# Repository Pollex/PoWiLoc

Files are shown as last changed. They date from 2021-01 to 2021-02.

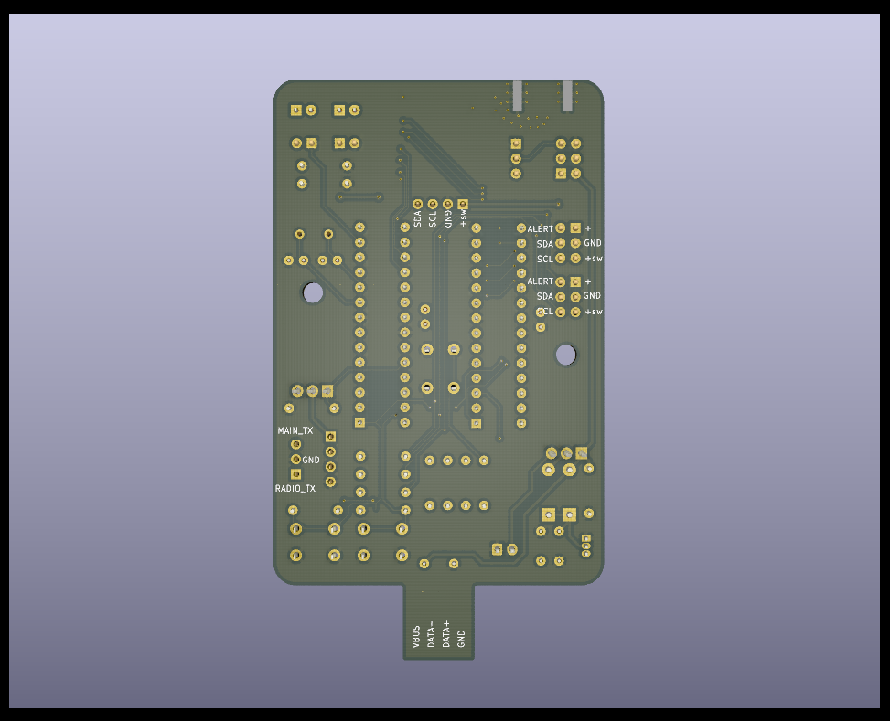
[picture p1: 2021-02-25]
hardware/exports/back_render.png

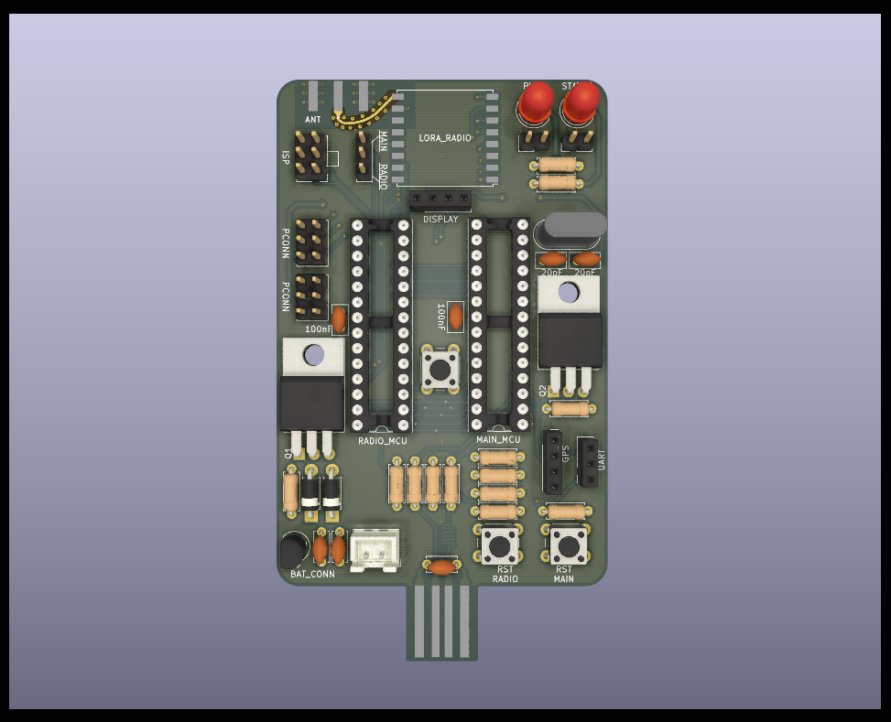
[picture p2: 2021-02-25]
hardware/exports/front_render.png

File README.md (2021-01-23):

# PoWiLoc
Pollex' Wireless Locator (PoWi Locator) is a fully Open-Source device used to test LoRaWAN connections and map them on the PoWi website and/or the [TTN Mapper](https://ttnmapper.org/) website.

The locator is designed to be built by everyone who has some technical knowledge (soldering and programming) and the device has several optional features which can be left out to make assembling the device easier.

The hardware is designed in free and Open-Source software called [KiCAD](https://kicad.org/).

The source code for this device is developed in [Visual Studio Code](https://code.visualstudio.com/) (a lightweight editor) with the [PlatformIO](https://platformio.org/) extension. Also both free and Open-Source. This setup is chosen instead of the Arduino IDE because it allows  for cleaner code and better library management.

## This project is in active development and contributions cannot be received at this point in time. As soon as a minimum viable product is built, contributions will open and links to documentation will be provided.

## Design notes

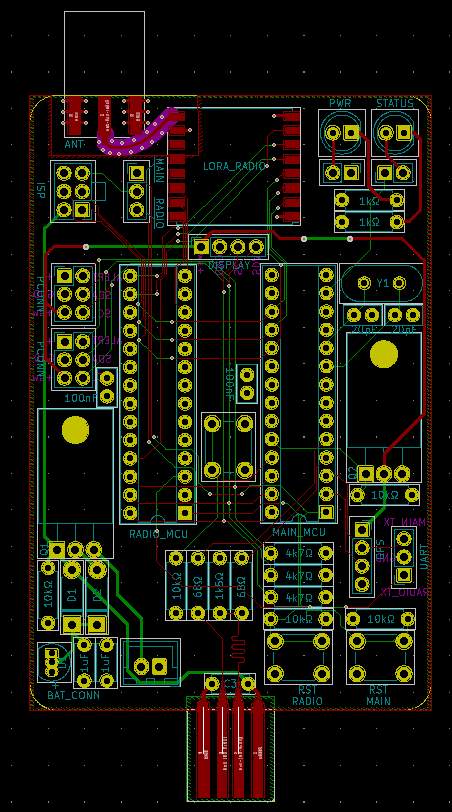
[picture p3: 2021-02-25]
hardware/exports/pcb.png

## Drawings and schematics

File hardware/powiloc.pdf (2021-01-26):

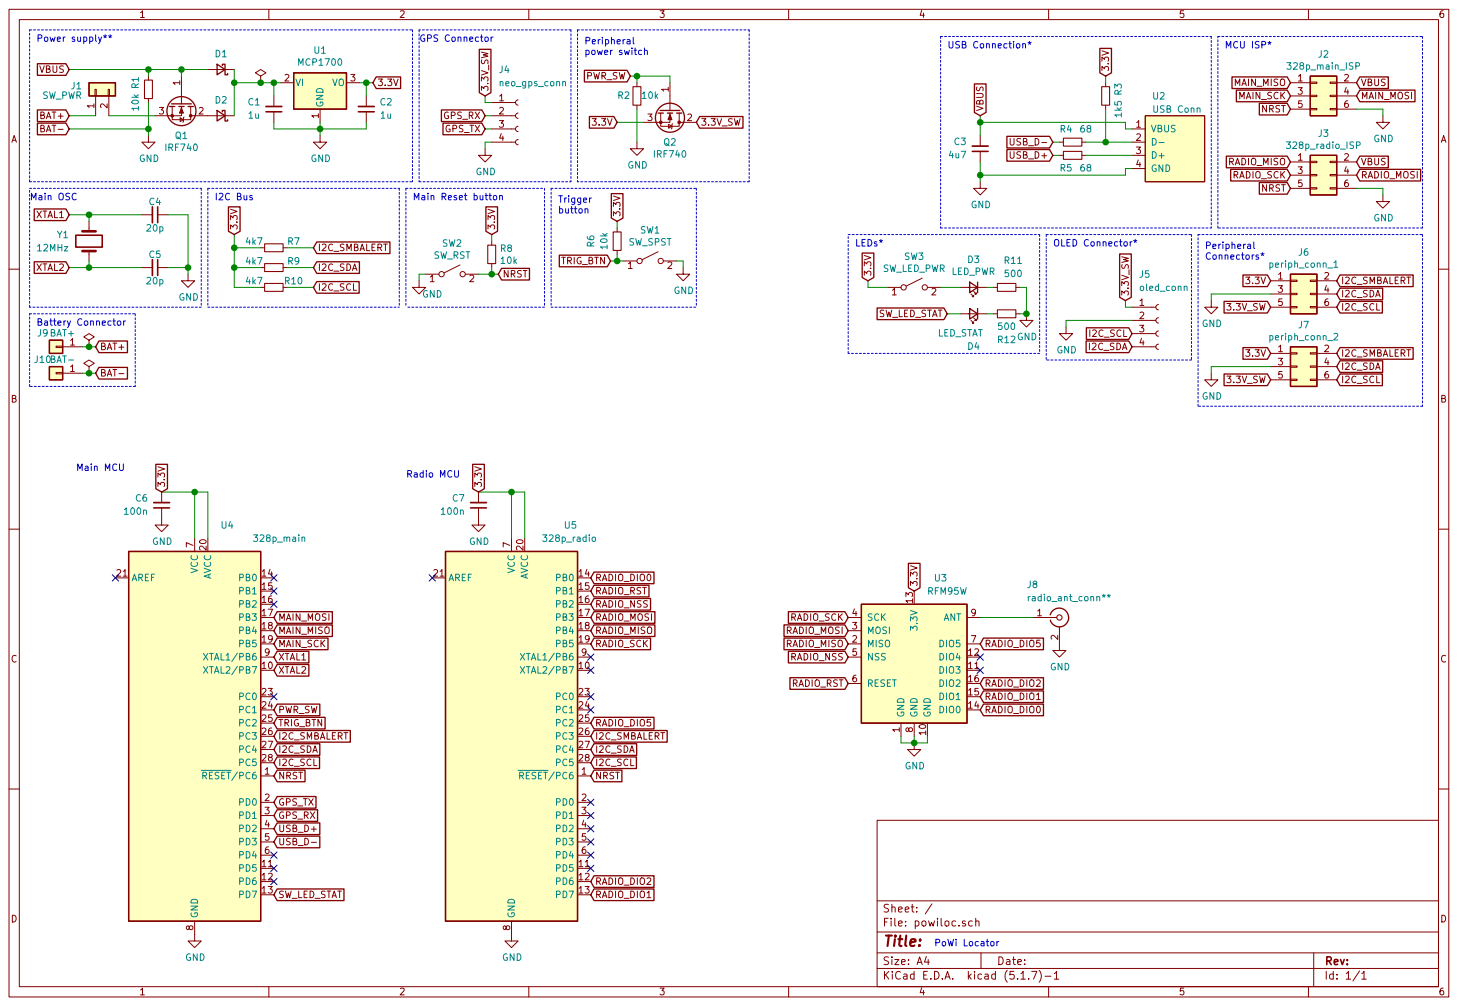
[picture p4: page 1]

1 GND 10 DIO3 11 DIO4 12 3.3V 13 DIO0 14 DIO1 15 DIO2 16 MISO 2 MOSI 3 SCK 4 NSS 5 RESET 6 DIO5 7 GND

File: powiloc.sch Sheet: /
Id: 1/1 Title:

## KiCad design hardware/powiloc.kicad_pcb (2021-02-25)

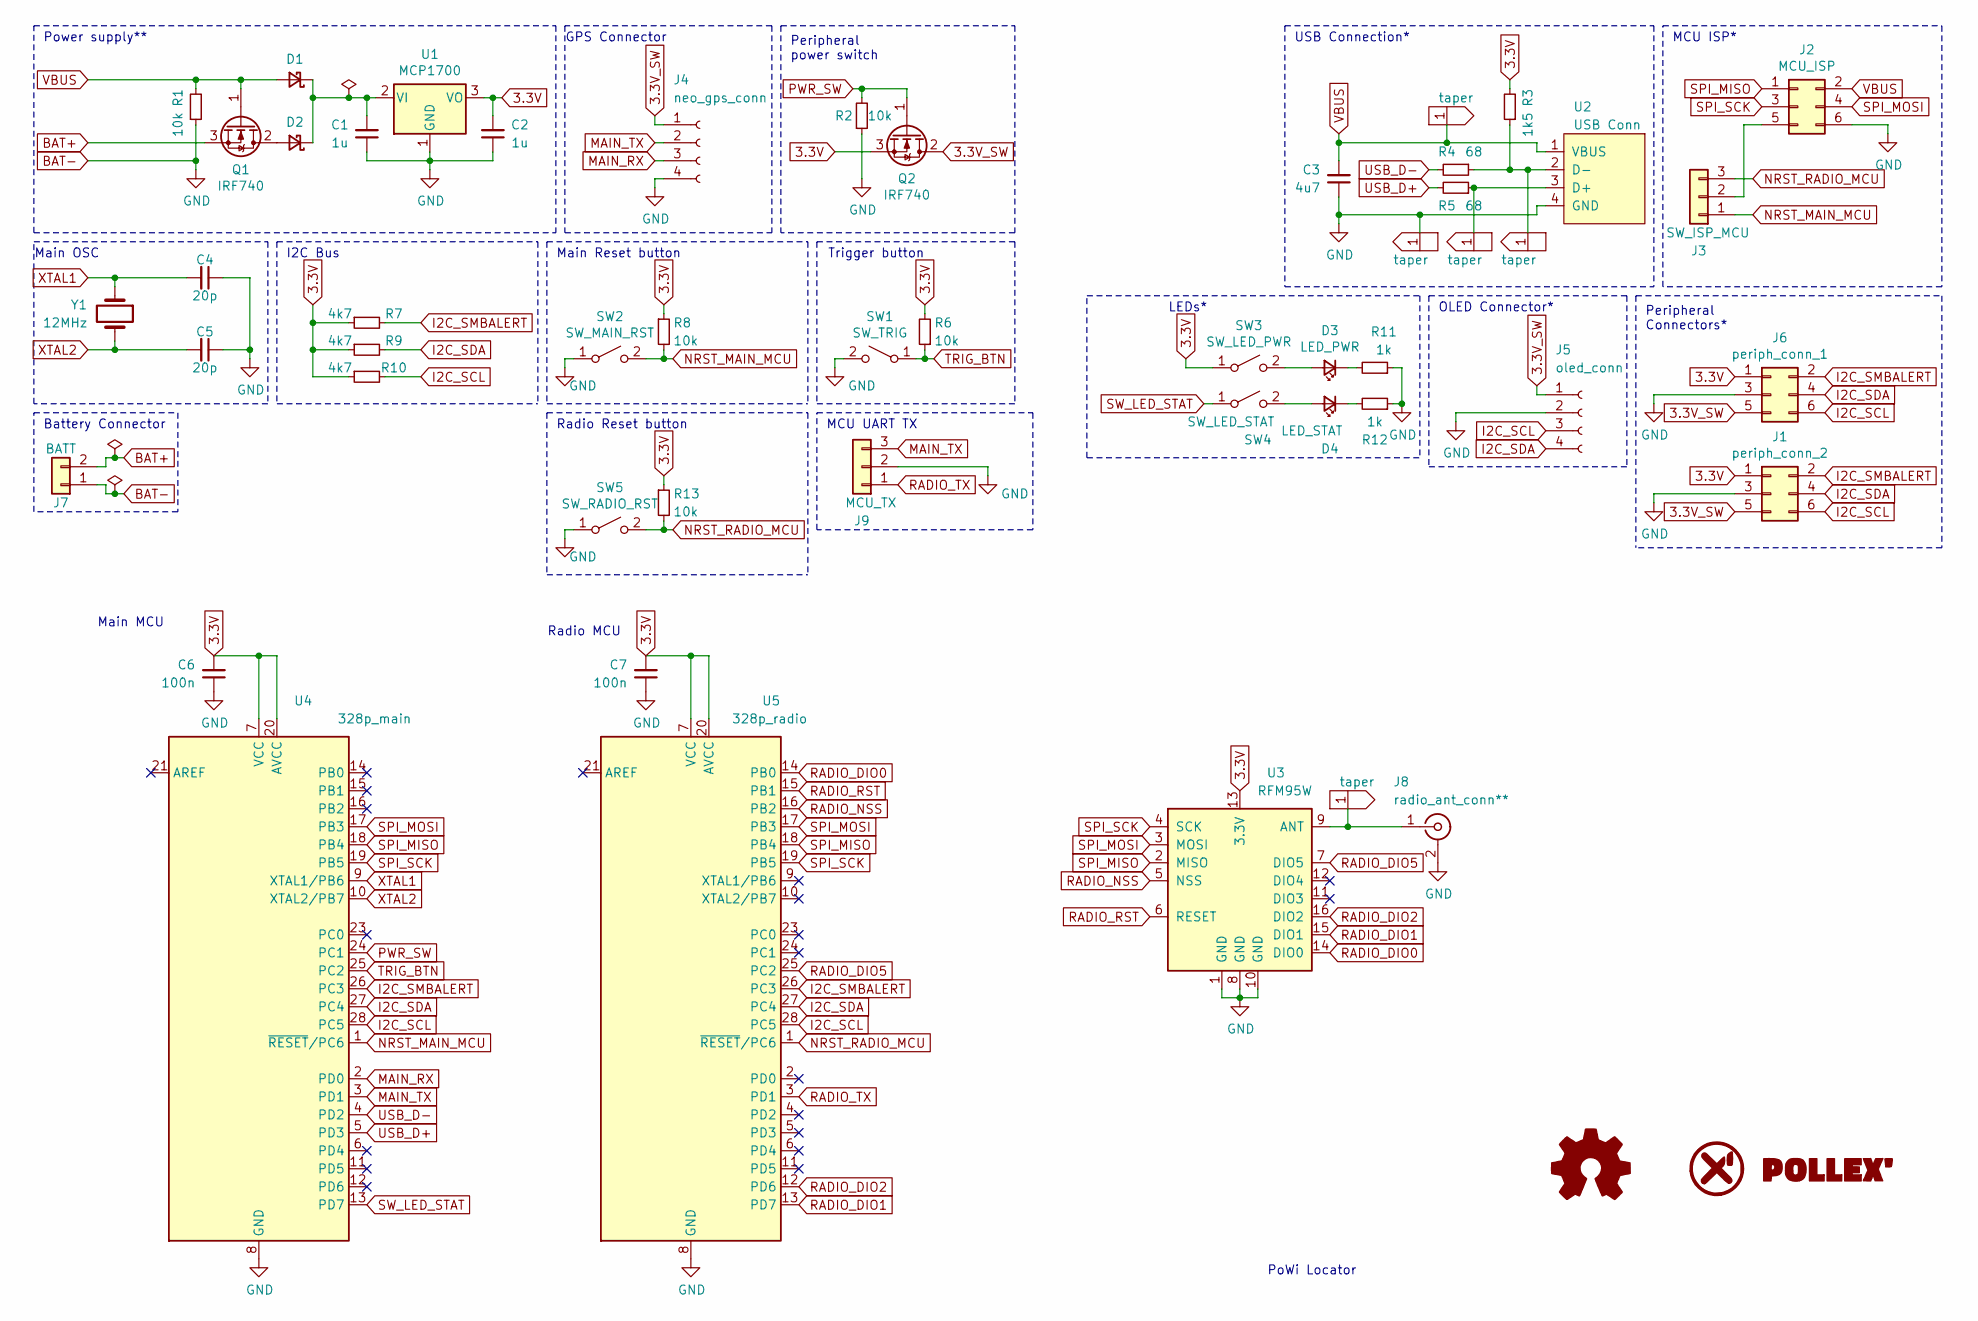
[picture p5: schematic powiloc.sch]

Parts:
C1, C2: 1u; C_Disc_D5.0mm_W2.5mm_P5.00mm
C3: 4u7; C_Disc_D5.0mm_W2.5mm_P5.00mm
C4, C5: 20p; C_Disc_D5.0mm_W2.5mm_P2.50mm
C6, C7: 100n; C_Disc_D5.0mm_W2.5mm_P2.50mm
D1, D2: D_Schottky_Small; D_DO-41_SOD81_P7.62mm_Horizontal
D3: LED_PWR; LED_D5.0mm
D4: LED_STAT; LED_D5.0mm
J1: periph_conn_2; PinHeader_2x03_P2.54mm_Vertical
J2: MCU_ISP; PinHeader_2x03_P2.54mm_Vertical
J3: SW_ISP_MCU; PinHeader_1x03_P2.54mm_Vertical
J4: neo_gps_conn; PinSocket_1x04_P2.54mm_Vertical
J5: oled_conn; PinSocket_1x04_P2.54mm_Vertical
J6: periph_conn_1; PinHeader_2x03_P2.54mm_Vertical
J7: BATT; JST_XH_B2B-XH-A_1x02_P2.50mm_Vertical
J8: radio_ant_conn**; SMA_Amphenol_132289_EdgeMount
J9: MCU_TX; PinSocket_1x03_P2.54mm_Vertical
Q1, Q2: IRF740; TO-220-3_Horizontal_TabDown
R1, R2, R6, R8, R13: 10k; R_Axial_DIN0207_L6.3mm_D2.5mm_P7.62mm_Horizontal
R3: 1k5; R_Axial_DIN0207_L6.3mm_D2.5mm_P7.62mm_Horizontal
R4, R5: 68; R_Axial_DIN0207_L6.3mm_D2.5mm_P7.62mm_Horizontal
R7, R9, R10: 4k7; R_Axial_DIN0207_L6.3mm_D2.5mm_P7.62mm_Horizontal
R11, R12: 1k; R_Axial_DIN0207_L6.3mm_D2.5mm_P7.62mm_Horizontal
SW1: SW_TRIG; SW_PUSH_6mm
SW2: SW_MAIN_RST; SW_PUSH_6mm
SW3: SW_LED_PWR; PinHeader_1x02_P2.54mm_Vertical
SW4: SW_LED_STAT; PinHeader_1x02_P2.54mm_Vertical
SW5: SW_RADIO_RST; SW_PUSH_6mm
T1, T2, T5: taper; uwT0.50_0.40_1.00_1.46_1.20
T3, T4: taper; uwT0.50_0.15_1.00_1.24_3.00
U1: MCP1700; TO-92_Inline
U2: USB Conn; USBPCB
U3: RFM95W; HOPERF_RFM9XW_SMD
U4: 328p_main; DIP-28_W7.62mm_Socket
U5: 328p_radio; DIP-28_W7.62mm_Socket
Y1: 12MHz; Crystal_HC49-U_Vertical

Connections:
3.3V: C2.2, C6.2, C7.2, J1.1, J6.1, Q2.3 (S), R3.2, R6.2, R7.1, R8.1, R9.1, R10.1, R13.1, SW3.1 (A), U1.3 (VO), U3.13 (3.3V), U4.7 (VCC), U4.20 (AVCC), U5.7 (VCC), U5.20 (AVCC)
3.3V_SW: J1.5, J4.1, J5.1, J6.5, Q2.2 (D)
BAT+: J7.2, Q1.3 (S)
BAT-: C1.1, C2.1, C3.1, C4.1, C5.1, C6.1, C7.1, J1.3, J2.6, J4.4, J5.2, J6.3, J7.1, J8.2 (Ext), J9.2, R1.1, R2.1, R11.1, R12.1, SW1.2 (B), SW2.1 (A), SW5.1 (A), T2.1, U1.1 (GND), U2.4 (GND), U3.1 (GND), U3.8 (GND), U3.10 (GND), U4.8 (GND), U4.22 (GND), U5.8 (GND), U5.22 (GND)
I2C_SCL: J1.6, J5.3, J6.6, R10.2, U4.28 (PC5), U5.28 (PC5)
I2C_SDA: J1.4, J5.4, J6.4, R9.2, U4.27 (PC4), U5.27 (PC4)
I2C_SMBALERT: J1.2, J6.2, R7.2, U4.26 (PC3), U5.26 (PC3)
MAIN_RX: J4.3, U4.2 (PD0)
MAIN_TX: J4.2, J9.3, U4.3 (PD1)
NRST_MAIN_MCU: J3.1, R8.2, SW2.2 (B), U4.1 (~RESET~/PC6)
NRST_RADIO_MCU: J3.3, R13.2, SW5.2 (B), U5.1 (~RESET~/PC6)
unnamed: C1.2, D1.1 (K), D2.1 (K), U1.2 (VI)
unnamed: D2.2 (A), Q1.2 (D)
unnamed: D3.1 (K), R11.2
unnamed: D3.2 (A), SW3.2 (B)
unnamed: D4.1 (K), R12.2
unnamed: D4.2 (A), SW4.2 (B)
unnamed: J2.5, J3.2
unnamed: J8.1 (In), T5.1, U3.9 (ANT)
unnamed: R3.1, R4.1, T4.1, U2.2 (D-)
unnamed: R5.1, T3.1, U2.3 (D+)
PWR_SW: Q2.1 (G), R2.2, U4.24 (PC1)
RADIO_DIO0: U3.14 (DIO0), U5.14 (PB0)
RADIO_DIO1: U3.15 (DIO1), U5.13 (PD7)
RADIO_DIO2: U3.16 (DIO2), U5.12 (PD6)
RADIO_DIO5: U3.7 (DIO5), U5.25 (PC2)
RADIO_NSS: U3.5 (NSS), U5.16 (PB2)
RADIO_RST: U3.6 (RESET), U5.15 (PB1)
RADIO_TX: J9.1, U5.3 (PD1)
SPI_MISO: J2.1, U3.2 (MISO), U4.18 (PB4), U5.18 (PB4)
SPI_MOSI: J2.4, U3.3 (MOSI), U4.17 (PB3), U5.17 (PB3)
SPI_SCK: J2.3, U3.4 (SCK), U4.19 (PB5), U5.19 (PB5)
SW_LED_STAT: SW4.1 (A), U4.13 (PD7)
TRIG_BTN: R6.1, SW1.1 (A), U4.25 (PC2)
USB_D+: R5.2, U4.5 (PD3)
USB_D-: R4.2, U4.4 (PD2)
VBUS: C3.2, D1.2 (A), J2.2, Q1.1 (G), R1.2, T1.1, U2.1 (VBUS)
XTAL1: C4.2, U4.9 (XTAL1/PB6), Y1.1
XTAL2: C5.2, U4.10 (XTAL2/PB7), Y1.2

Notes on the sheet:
Main OSC
Main MCU
Main Reset button
PoWi Locator
USB Connection*
Power supply**
MCU ISP*
GPS Connector
OLED Connector*
Trigger button
Radio MCU
I2C Bus
Peripheral power switch
LEDs*
Peripheral Connectors*
Battery Connector
Radio Reset button
MCU UART TX

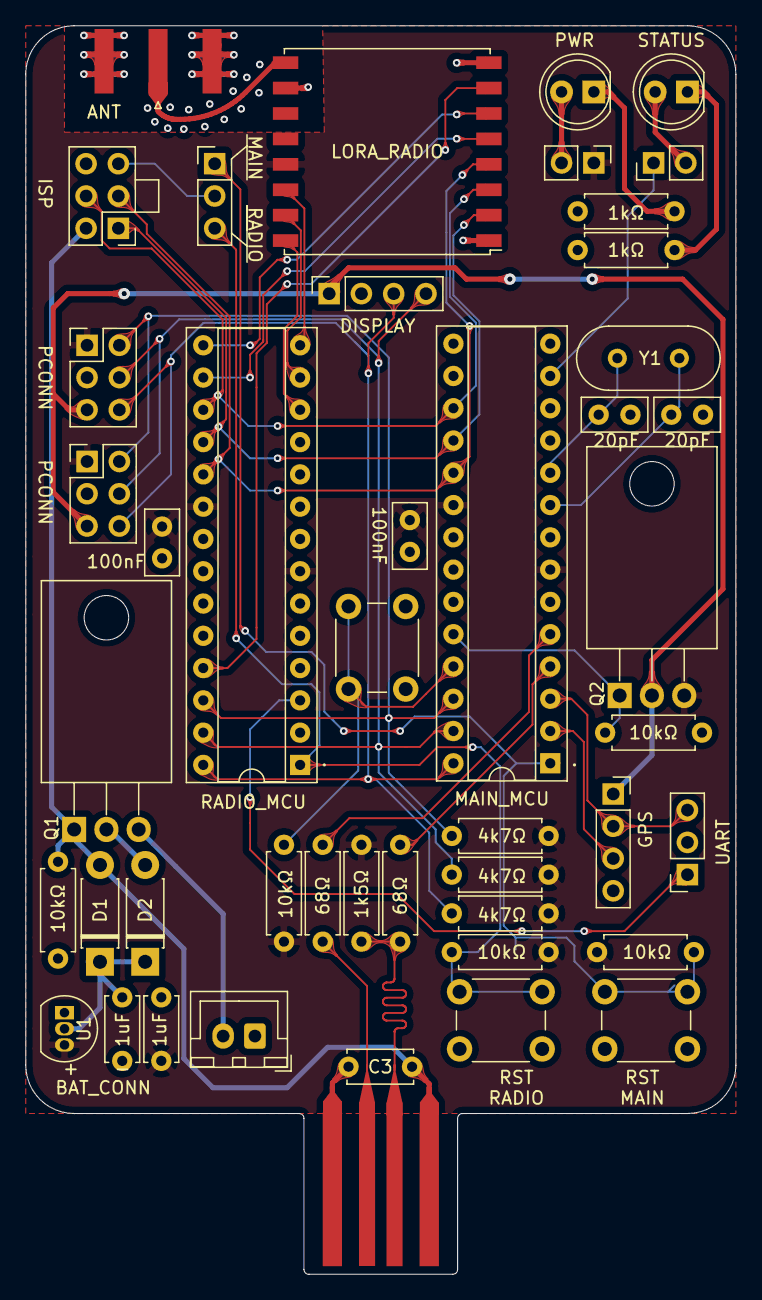
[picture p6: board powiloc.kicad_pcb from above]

Board: 2 copper layers, 55.9 x 98.2 mm, 51 parts (0 on the bottom side), 39 nets.

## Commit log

2021-01-23 Add hardware files
    [powiloc.kicad_pcb, powiloc.sch]
2021-01-26 Update schematic design
    [powiloc.kicad_pcb, powiloc.sch]
2021-01-26 PCB Placement
    [powiloc.kicad_pcb, powiloc.sch]
2021-01-29 Corrupt save
    [powiloc.kicad_pcb, powiloc.sch]
2021-02-25 Update production
    [powiloc-B_Cu.gbr, powiloc-B_Mask.gbr, powiloc-B_Paste.gbr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]
